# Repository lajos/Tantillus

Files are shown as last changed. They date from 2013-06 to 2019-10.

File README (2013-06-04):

My Tantillus build, with some changes and experiments:

  - Oilite bearings (replacing lm8uus and printed bushings)
  - all 5/16" rods
  - panel joints changed to 0.25" US stock (I used MDF)
  - split panels (the panels were just a bit too large for my CNC machine, so I added a joint in the middle)
  - corners for 0.25" US stock
  - corners with no tabs
  - offset spur gears (to reduce noise)

Tantillus

Introducing Tantillus. The portable self replicating mini printer.

Please visit www.Tantillus.org for more information

** Please note these files may change without notice **

If you find mistakes or convert it to metric please file a bug report here on GitHub or even better a pull request.

- Derived parts: -
	4   -   Triffidhunter's Printable LM8uu v3 bushings http://www.thingiverse.com/thing:16813

- One piece case (200mm x 200mm x 300mm) -
	1   -   Tantillus.0.2.0.stl

NOTE: See image folder for exploded view of printed case.

- Printed Case files: -

	- Printed case source: -
	Tantillus.0.1.1.blend
	Tantillus.0.1.1_ABS.blend

       1   -   Case top 1
       1   -   Case top 2
       1   -   Case top 3
       1   -   Case top 4
       1   -   Case middle 1
       1   -   Case middle 2
       1   -   Case middle 3
       1   -   Case middle 4
       1   -   Case bottom 1
       1   -   Case bottom 2
       1   -   Case bottom 3
       1   -   Case bottom 4

- Printed case connectors: -

       1   -   Top front connector
       2   -   Top side connectors
       1   -   Rear lower connector
       1   -   Rear upper connector
       3   -   Middle connectors
       3   -   Base connectors
       1   -   Motor mount reinforcement
       4   -   Upper stiffeners

NOTE: Assembled and exploded view stl files are for reference only.

- Axis Parts: -

	1  -  Bowden clamp.stl
	1  -  Carriage bottom.stl
	1  -  Carriage top.stl
	1  -  Endstop_holder.stl
	4  -  Printable-lm8uu-v3.stl
	2  -  XY_end_left.stl
	2  -  XY_end_right.stl
	1  -  Z_arm_1.stl
	1  -  Z_arm_2.stl
	2  -  Z-coupler.stl
	1  -  Z_lift.stl
	1  -  Z_lower_bracket.stl
	1  -  Z_motor_bracket.stl
	1  -  Z_upper_bracket.stl

- Extruder: -

	1  -  Extruder.stl
	1  -  Extruder_idler.stl
	1  -  Extruder_motor_mount_v2.stl 

- Gears: - 

NOTE: 4mm and 5mm denote motor shaft size (use only one size)

	2  -  Upper gear.stl
	2  -  Motor_gear_(4mm).stl
	or
	2  -  Motor_gear_(5mm).stl

NOTE: Two sets of gears included for the extruder. 
The Herringbone gears are hard to print and need a highly calibrated machine to do so.

	1  -  Extruder_large_v2.stl 		(normal gears 2.7:1)
	1  -  Extruder_small_v2_(4mm).stl	(normal gears 2.7:1)
	or
	1  -  Extruder_small_v2_(5mm).stl	(normal gears 2.7:1)

	OR

	1  -  Extruder_large.stl	(Herringbone gears 3.3:1 (very hard to print)
	1  -  Extruder_small_(4mm).stl	(Herringbone gears 3.3:1 (very hard to print)
	or
	1  -  Extruder_small_(5mm).stl	(Herringbone gears 3.3:1 (very hard to print)

- Laser cut case files: - 

NOTE: STL's are used to produce the DXF's and SVG's and are not for printing.

	All_panels.dxf
	All_panels.stl
	All_panels.svg
	
	Back.dxf
	Back.stl
	Back.svg

	Carriage_middle.dxf
	Carriage_middle.stl
	Carriage_middle.svg

	Front.dxf
	Front.stl
	Front.svg

	Left.dxf
	Left.stl
	Left.svg

	Right.dxf
	Right.stl
	Right.svg

NOTE: Cutting test to confirm fit of tabs and bearings

	Test.dxf
	Test.svg
	test.stl

NOTE: Scad file used to make DXF's from STL's (Inkscape used to convert DXF's to SVG's)

	V3_svg.scad

- Laser cut case corners -

	4  -  Corner_bottom.stl
	1  -  Corner_top_front_left.stl
	1  -  Corner_top_front_right.stl
	1  -  Corner_top_rear_left.stl
	1  -  Corner_top_rear_right.stl

- Extras -

NOTE: Not all of these are used for each machine choose wisely
(LC) = Laser cut

	40mm_fanmount_(LC).stl
	50mm_fanmount_(LC).stl
	40mm_Fan_mount_(printed case).stl
	Encoder_knob.stl
	40mm_Fan_duct.stl
	Plug_adapter.stl
	Repraper_spool_a.stl
	Repraper_spool_b.stl
	Spool_holder.stl 	(Esun style spool)
	Spool_holder_long.stl 	(Makerbot spool)
	Spool_holder_mount.stl	(Fits both Esun and Makerbot spool holder)

- Source files -

	Tantillus.0.3.4.blend (laser cut case and all axis parts)

	40mm_Fan_duct.blend
	All_Fanmounts.blend
	Extruder_gears_v2.blend
	Plug_adapter.blend
	Spool_holders.blend
	Tantillus_extruder.blend
	Tantillus_gears.blend

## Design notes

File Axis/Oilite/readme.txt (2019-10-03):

These parts use Oilite lubricated bronze sleeve bearings instead of the lm8uus and printed bushings.

Benefits:
  - no maintanence (the bearings are magically self lubricating)
  - zero noise
  - no play
  - all rods are the same size, 5/16"
  - oilites are easy to find (probably even your hardware store has them)

Cons:
  - none so far

All rods are 5/16". No 8mm rods used.

Bearings 5/26" ID x 1/2" OD:
  - x/y ends: 1", 4 pcs (mcmaster 6391K443)
  - carriage: 1" or 1.25", 4 pcs (mcmaster 6391K443 or 6391K444)
  - cable z: 0.5", 4 pcs (mcmaster 6391K405)

Notes:

  - The bearings fit snugly in the printed parts. If the holes are too tight, drill them out with 1/2" drill bit.

  - Don't drill into the bearings for the XY ends. Make sure the #8 screw doesn't touch the bearings. Either use a smaller one or cut it shorter.

  - Two 1/2" bearings go into each z-arm. Each oilite is sandwiched between two spacers, that are glued in place. Don't glue the oilites.

  - I currently have 1" oilites in the carriage.

The oilites need a short break in period so they get their juices going. When first assembled the carriage should slide free and without binding, but after an hour or two of printing things will get even silkier smoother.

The corners fit US 1/4" stock (somewhere around 6.5), for example MDF.

My panels were routed on a CNC machine and I could never get the tabs to work. If you use the set of corners without tabs, make sure your case is glued.

Future:
  - try 7/16" or 3/8" OD oilites (cheaper, less weight)
  - improve z arm mounting (no need for zip tie holes, create pockets for oilites)
  - reduce carriage size (bearings are shorter than carraige)

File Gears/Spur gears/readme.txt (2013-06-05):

I wanted quieter gears, so made these spur gears out of MDF on a CNC machine.
Each gear is made up of two pieces, slightly offset so they act similar to the herring bone gears.

The sets have two of the gears flipped. This is useful if cutting on CNC machine where the stock first has to be planed to the desired width.

To make:
  - cut 4 pieces of upper and 4 pieces of lower gear halves
  - the absolute maximum width of the stock is 4mm with the official Tantillus rod lengths
  - print 2 upper and 2 lower clamps

Hardware:
  - 8 pcs #8-32 x 3/8" set screws
  - 8 pcs #8-32 square nuts, or regular hex nuts with one side filed off
  - 8 pcs #4-40 x 1/2" screws
  - 8 pcs #4-40 nuts

Assembly:
  - optional: size the mdf with 1:4 yellow wood glue:water mix
  - align gear halves using the #4 holes
    - gear teeth should be offset from each other (where there's a tooth on one gear, there should be a hole on the other)
  - assemble two halves and the clamp with #4 screws

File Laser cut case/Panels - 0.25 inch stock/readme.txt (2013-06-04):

Case diles modified to work with US 1/4" stock (around 6.5mm).

one_piece: these are the hole panels

joint: my CNC could not fit the whole panels, so I added a joint and made each panel from two pieces. Use two maters on each side to hold the panels while the glue sets.

aligner: I glued my case, used two of these (one on top, one bottom) to make sure the frame square (car tie downs to clamp while drying).

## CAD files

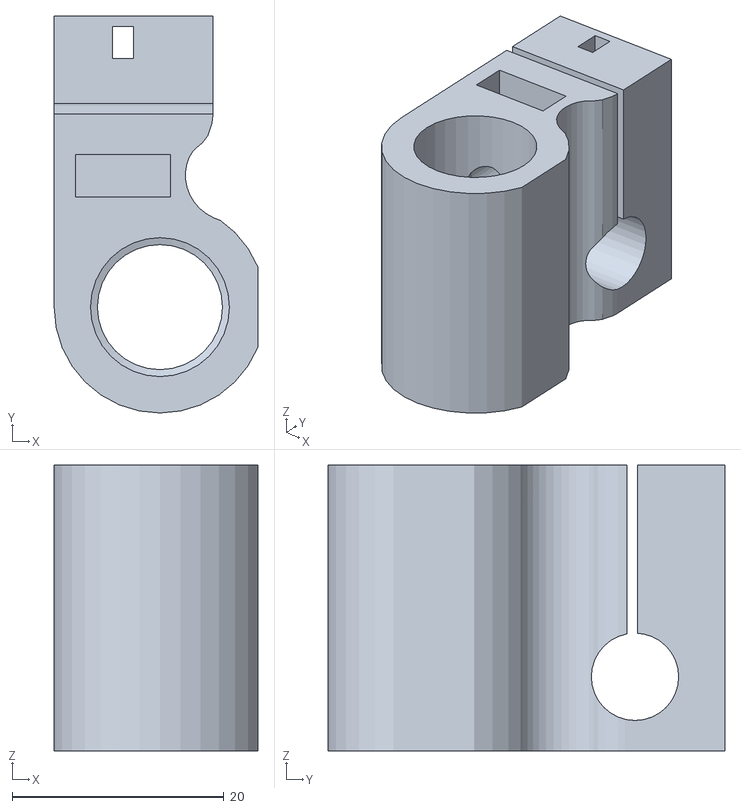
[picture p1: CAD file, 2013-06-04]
Axis/Oilite/xy_oilite_right.stl
19.3 x 37.5 x 27.0

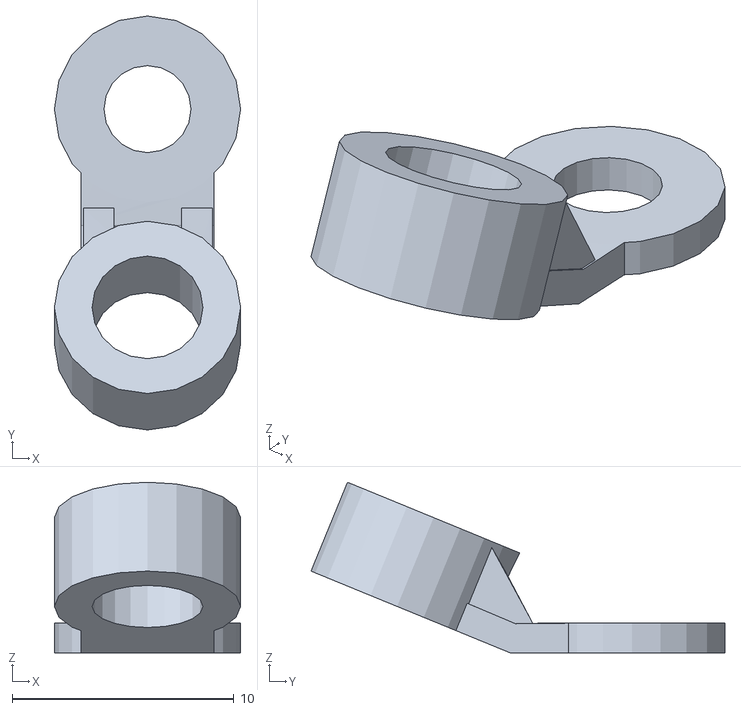
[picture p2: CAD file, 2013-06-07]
Extras/Carriage_led_mount_more_bend.stl
8.40 x 18.7 x 7.69

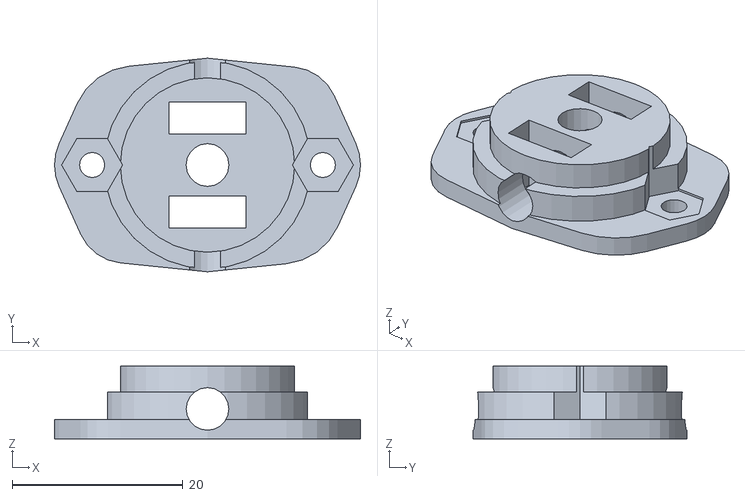
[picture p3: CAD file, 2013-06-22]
Gears/Spur gears/mount_motor_5mm.stl
35.8 x 25.0 x 8.50

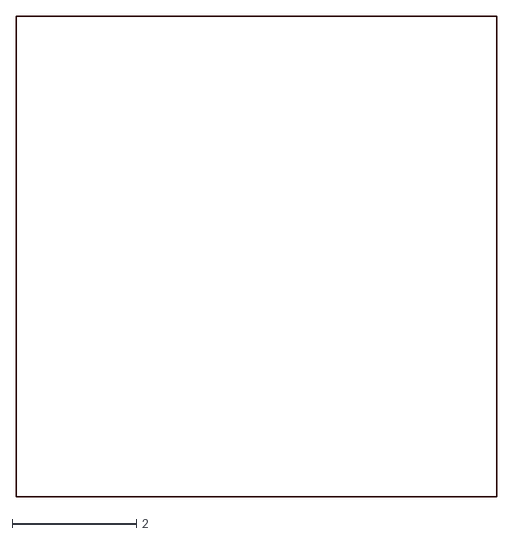
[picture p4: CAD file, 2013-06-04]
Laser cut case/Panels - 0.25 inch stock/aligner.dxf
7.72 x 7.72

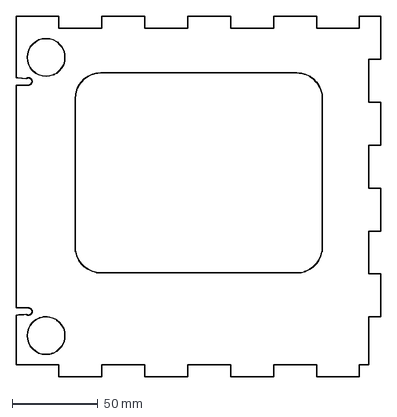
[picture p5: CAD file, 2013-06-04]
Laser cut case/Panels - 0.25 inch stock/joint/left_a.dxf
212.5 x 209.8 mm

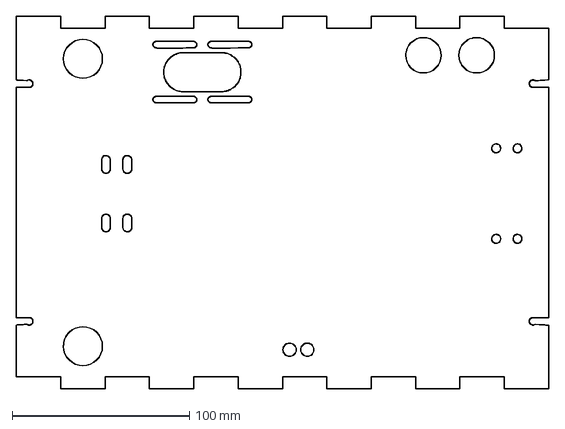
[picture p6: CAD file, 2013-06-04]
Laser cut case/Panels - 0.25 inch stock/one piece/back.dxf
300.0 x 209.8 mm

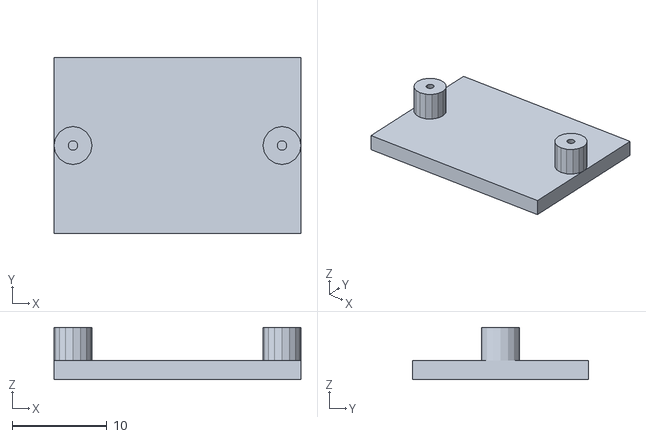
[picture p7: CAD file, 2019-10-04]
Oilite + Metal Hotend Parts/LED_driver_mount.stl
26.0 x 18.5 x 5.49

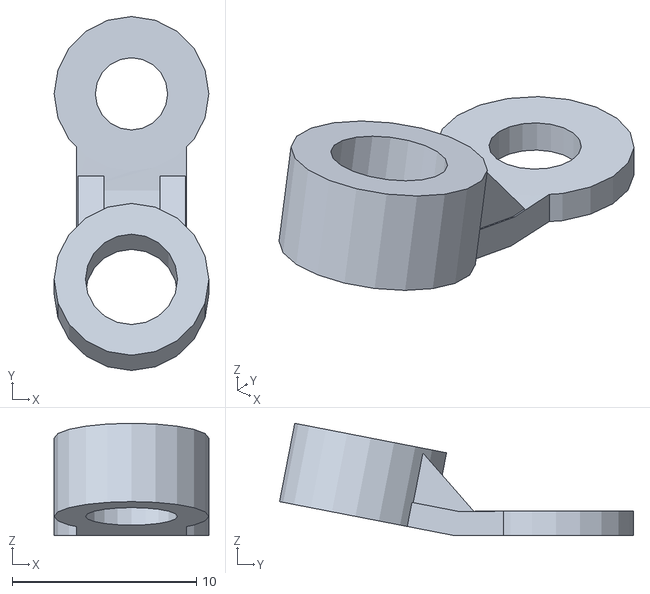
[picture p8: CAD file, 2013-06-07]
Extras/Carriage_led_mount.stl
8.40 x 19.2 x 6.10

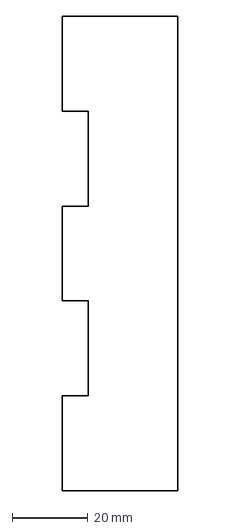
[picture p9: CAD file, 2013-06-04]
Laser cut case/Panels - 0.25 inch stock/joint/mater.dxf
30.4 x 125.0 mm

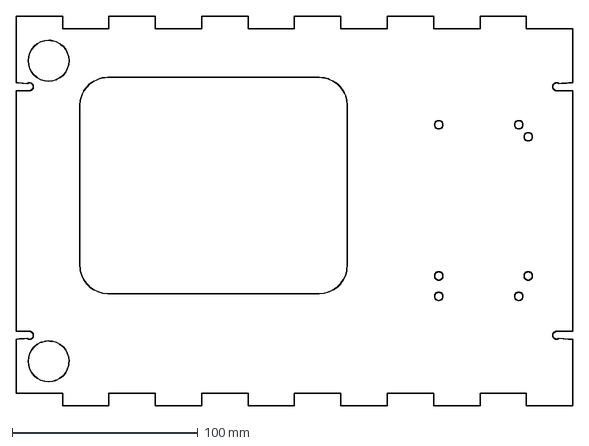
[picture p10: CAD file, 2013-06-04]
Laser cut case/Panels - 0.25 inch stock/one piece/left.dxf
300.0 x 209.8 mm

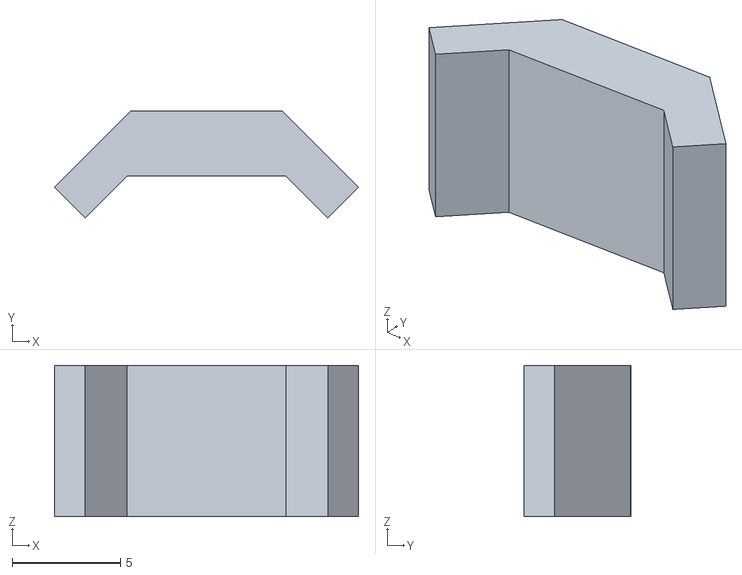
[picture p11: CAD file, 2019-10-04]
Oilite + Metal Hotend Parts/LED_wire_holder.stl
14.1 x 4.95 x 7.00

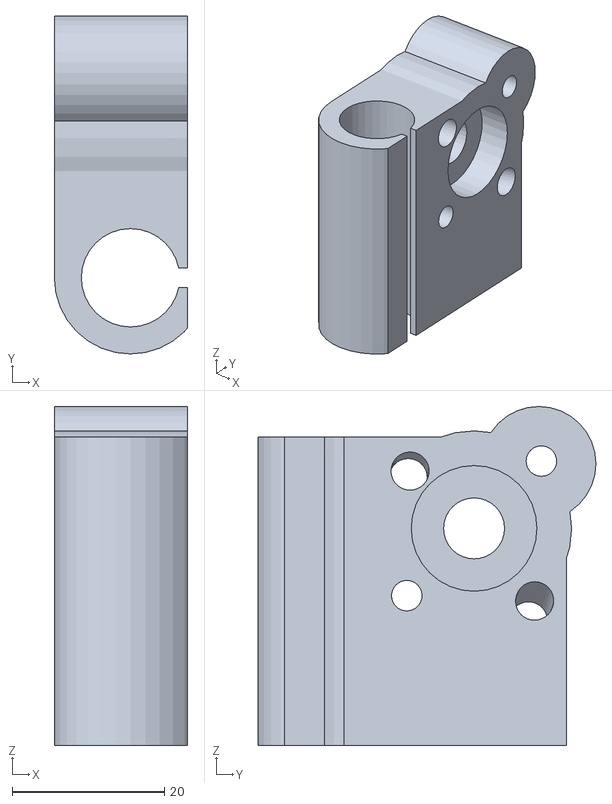
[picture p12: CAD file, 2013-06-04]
Axis/Oilite/carriage_oilite_top.stl
17.5 x 44.4 x 44.5

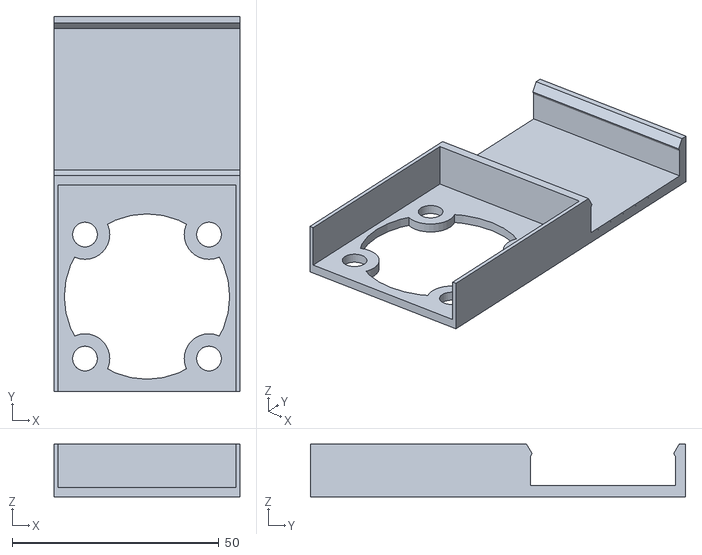
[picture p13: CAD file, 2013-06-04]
Extras/40mm_fanmount_(LC)_0.25_inch_stock.stl
45.0 x 90.8 x 12.8

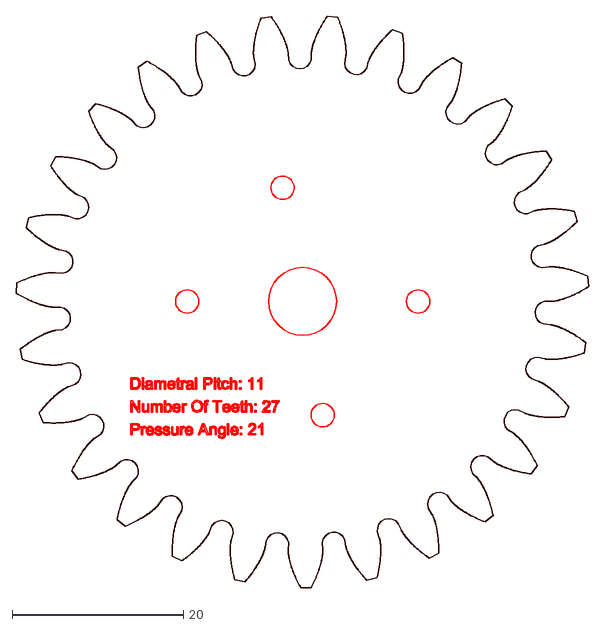
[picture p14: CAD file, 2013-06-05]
Gears/Spur gears/upper_gear.dxf
66.9 x 66.8

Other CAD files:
Axis/Oilite/xy_oilite_left.stl
Gears/Spur gears/mount_motor_4mm.stl
Laser cut case/Panels - 0.25 inch stock/joint/right_b.dxf
Laser cut case/Panels - 0.25 inch stock/one piece/front.dxf
Axis/Oilite/carriage_oilite_bottom.stl
Extras/50mm_fanmount_(LC)_0.25_inch_stock.stl
Gears/Spur gears/motor_gear.dxf
Gears/Spur gears/motor_gear_clamp.stl
Gears/Spur gears/motor_gear_half.dxf
Gears/Spur gears/motor_gear_set.dxf
Gears/Spur gears/mount_upper.stl
Gears/Spur gears/upper_gear_half.dxf
Gears/Spur gears/upper_gear_set.dxf
Laser cut case/Corners - 0.25 inch stock/with tabs/corner_bottom.stl
Laser cut case/Corners - 0.25 inch stock/with tabs/corner_top_front_left.stl
Laser cut case/Corners - 0.25 inch stock/with tabs/corner_top_front_right.stl
Laser cut case/Corners - 0.25 inch stock/with tabs/corner_top_rear_left.stl
Laser cut case/Corners - 0.25 inch stock/with tabs/corner_top_rear_right.stl
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

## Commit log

2013-06-04 0.25" corners, oilite parts
    [40mm_fanmount_(LC)_0.25_inch_stock.stl, 50mm_fanmount_(LC)_0.25_inch_stock.stl, carriage_oilite_bottom.stl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]
2013-06-04 mdf spur gears
    [mdf_gear_clamp_motor.stl, mdf_gear_clamp_upper.stl, motor_gear.dxf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]
2013-06-04 0.25" panels
    [aligner.dxf, back.dxf, back_a.dxf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]
2013-06-04 updated readme, renamed spur gear files
    [motor_gear_clamp.stl, motor_gear_half.dxf, upper_gear_clamp.stl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]
2013-06-05 updated spur gears, added gear sets with flipped halves
    [motor_gear.dxf, motor_gear_set.dxf, upper_gear.dxf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]
2013-06-07 carriage led mount
    [Carriage_led_mount.stl, Carriage_led_mount_more_bend.stl]
2013-06-22 spur gear mounts
    [mount_motor_4mm.stl, mount_motor_5mm.stl, mount_upper.stl]
2019-10-03 redoing xy with better sliders, extruder from ender5, metal hotend and t8 z axis
    [LED_holder.blend, LED_holder.stl, bed_adjust_knob.blend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]
2019-10-04 led holder
    [LED_driver_mount.blend, LED_driver_mount.stl, LED_holder.blend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]
